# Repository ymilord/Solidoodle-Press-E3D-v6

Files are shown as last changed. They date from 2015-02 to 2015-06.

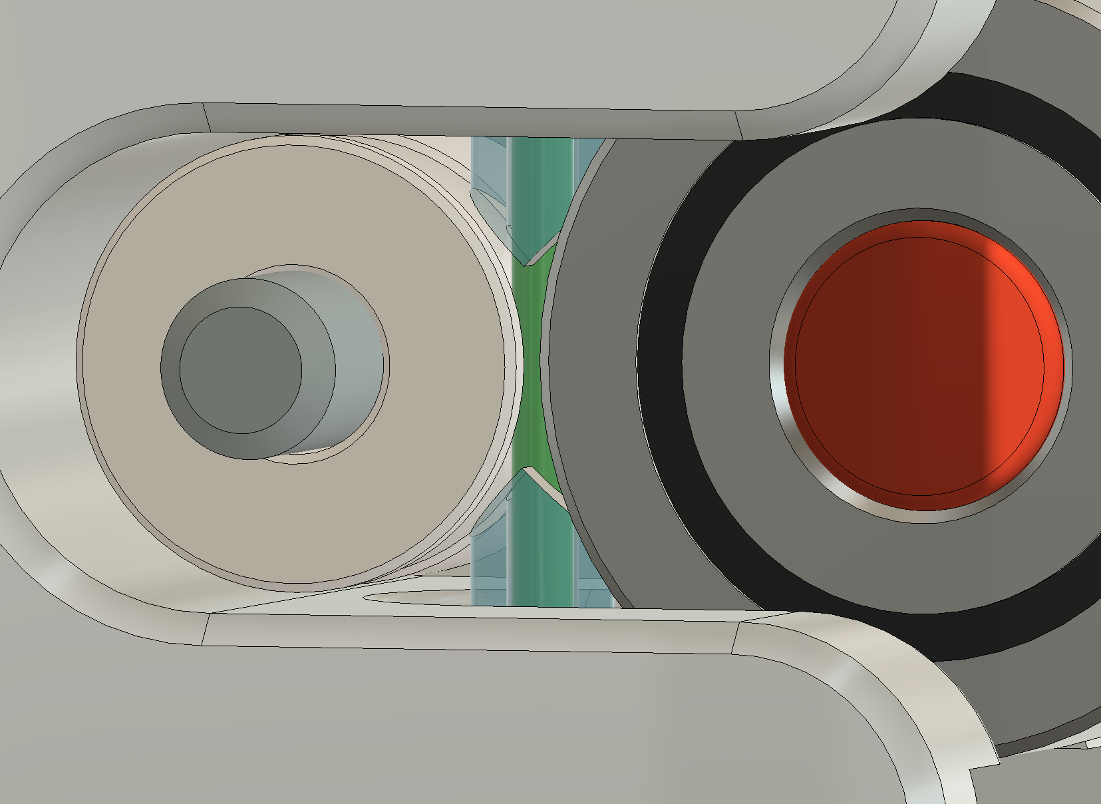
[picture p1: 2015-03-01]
Parts/Direct/SD2/Standard/SD2_Dual_PTFE_Tubes.jpg

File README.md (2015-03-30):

# E3D v6 Ready Firmware & Parts for the Soildoodle Press/SD2

This repo will have two versions. One Bowden and one direct drive. The in Firmware folder I've place a dump of the stock (shipping) firmware for the Press & a E3D Prepped verison. 

The main difference between the *Bowden* and the *Direct Drive* (aside from the bowden itself) is the Z-Height loss. In the bowden, Nothing changes - you will have the full 203mm travel for printing. For the Non-Bowden you will lose about 68mm of Z-Travel. So adjust your slicer app accordingly.

<b>Notice :</b> This is for the folks that are experienced in uploading arduino sketches/hex files to AVR's. If any of this sounds foreign or complicated- Not not attempt. <b>I will not provide support. Any damages/issues that you cause will be at your own risk.</b> (Sorry, got to say it.)

<b>Installation :</b>

This was done with a USBTinyISP connected to a RPI B+. (If you are using OctoPi and have a USBTinyISP this is by far the easiest method.) Of course there are other methods to do this. Use what ever workflow works best for you. This is a document of what I've done.

On the Press' controller, The right header is for the *ATTINY2313* (Pin 1 is right) the left header is for the *AT90USB1286* (Pin 1 is left). The *ATTINY2313* can be pulled directly (no jumpers) but the *AT90USB1286* needs a jumper in JP1 in order for you to read/write the firmware via the ICSP header.

If you want to make your own backup of the stock firmware, On the RPi create a folder where you'd like to store the backup. If you are using OctoPi I'd suggested creating a folder tree ~/pi/Press_Firmware/Stock/ & ~/pi/Press_Firmware/Modded/. 'Stock' to store the backup and 'Modded' to store the firmware provided here. 

To create your own backup run:

cd ~/pi/Press_Firmware/Stock/

avrdude -c avrisp -b 250000 -i 10 -p AT90USB1286 -P /dev/ttyACM0 -F -U flash:r:factory_press_AT90USB1286.hex:i

This will read the firmware on the Press and dump that data to a HEX file called 'factory_press_AT90USB1286.hex' in that folder.

To flash the modified firmware to the Press navigate to the folder where you placed the modded firmware. (i.e. ~/pi/Press_Firmware/Modded')

And run: 

avrdude -c avrisp -b 250000 -i 10 -p AT90USB1286 -P /dev/ttyACM0 -F -U flash:w:Solidoodle_Press_Modified_Firmware.cpp.hex:i

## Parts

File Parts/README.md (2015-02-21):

# Parts for Press.
STL & STEP files.

Printed @  0.2mm Layer height - 20% Infill - *8 Perimeters* - *8 Solid layers Top & Bottom* (*That's optional - I just used the same profile I use to print mounts of any kind. Just my personal preference.*) All designed to be printed as-is no supports.

This is a WIP (Work-In-Progess). I've uploaded the STL's & STEP files for the Bowden Config for the SD Press. The STEP's for the non-bowden soon to follow (I need to clean then up and label everything) As for the Non-Bowden verison. I am still designing the plug-in for the Z-Probe.

In the firmware folder, It has the INO & a precomplied HEX with changes to support the E3D v6 on the Press. Nothing else. 

Additional Parts Need :

Both : E3D v6 Universal /w Bowden Extras (Comes with a bowden tube) Then request either the 24V @ 25W or the 24V @ 40W Heater Cartridge. > http://www.filastruder.com/products/all-metal-e3d-v6-hotend
And x1 - VHR-2N - CONN HOUSING VH 2POS 3.96MM WH > http://www.digikey.com/product-search/en?mpart=VHR-2N&vendor=455
Bowden setup:

x2 M4 Screws @ 30mm - 2x M4 Nuts - 4x M3 Screws @ 30mm - x1 608ZZ bearing - x1 Spring (anything about 11mm in diameter) x2 Push-to-Connect Fitting (http://www.amazon.com/gp/product/B00PN5G2NQ/)

Non-Bowden Setup:

3x M3 Screws @ 30mm - 1x 608ZZ Bearing - 1x Spring (see above) 
I use a short piece of PTFE tubing that have a "V" shape at the top (see the example image for details.)

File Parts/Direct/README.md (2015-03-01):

This is a WIP - As in I am (as you read this) still finalizing the parts for this. This verison will work- But use at your own risk.

Added mount kit for the SD2. Same design and concept of the Press mount with an additional mount screw and a PTFE tube at the top for better flexible filament performance. This same updates will be applied to the Press Non-Bowden mount soon.
 
 **NOTE** : On the Press, I am still tweaking the mount/plug-in for the Z-Endstop for the Press to accomdate the height difference between the E3D v6 and the stock extruder. Also be mindful of the fact that you will lose some Z-height with this mod.

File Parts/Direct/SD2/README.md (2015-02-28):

This is a plate that attaches to the stock carriage to accept the non-bowden mount for an E3D v6. This plate has a 
wire channel for the connections for the heater cart. & thermistor.

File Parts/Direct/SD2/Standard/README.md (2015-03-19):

This is the SD2 E3D v6 mount for the standard hobbed gear.

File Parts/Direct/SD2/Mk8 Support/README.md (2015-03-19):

This is the SD2 E3D v6 mount with Mk8 support. This updated design has a PTFE tube in the lever to provide a better smoother path for flexible filaments like NinjaFlex. There is also a updated back plate thats thicker to prevent flex in the extruder assembly.

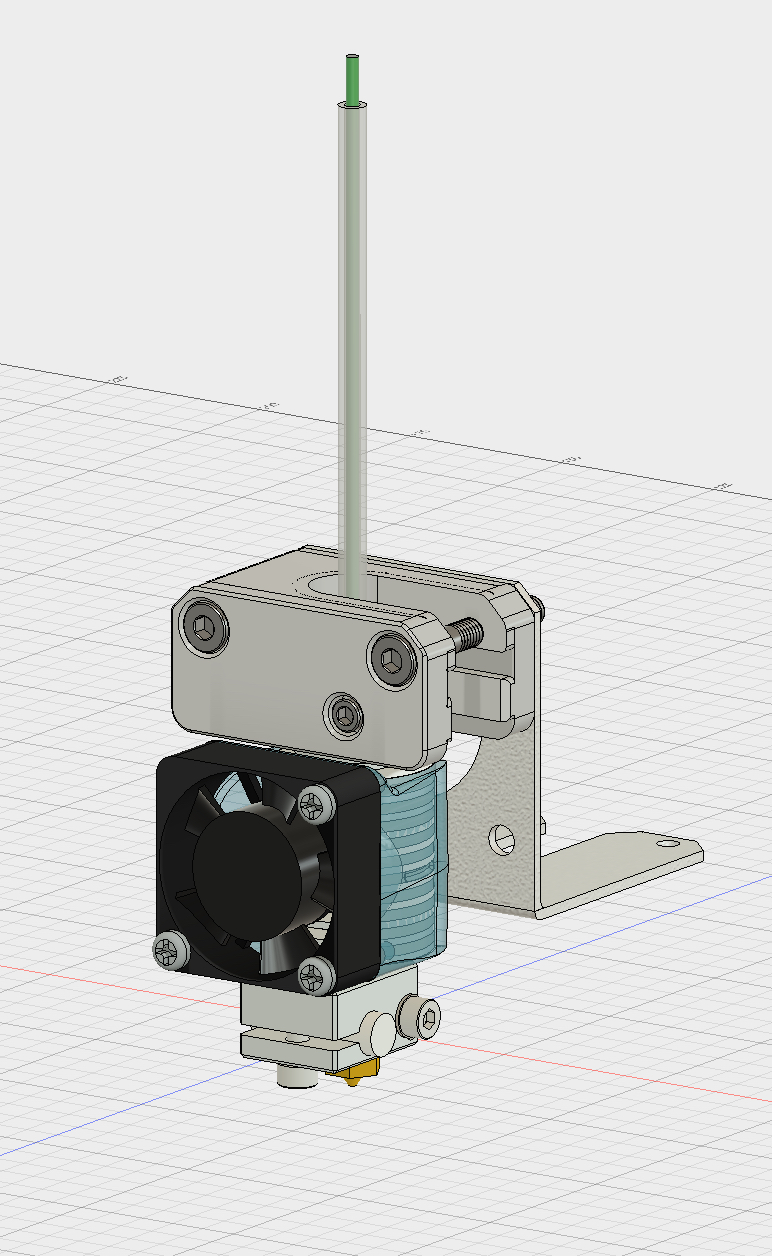
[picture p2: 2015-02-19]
Parts/Bowden/E3D_v6_Press_Mount.jpg

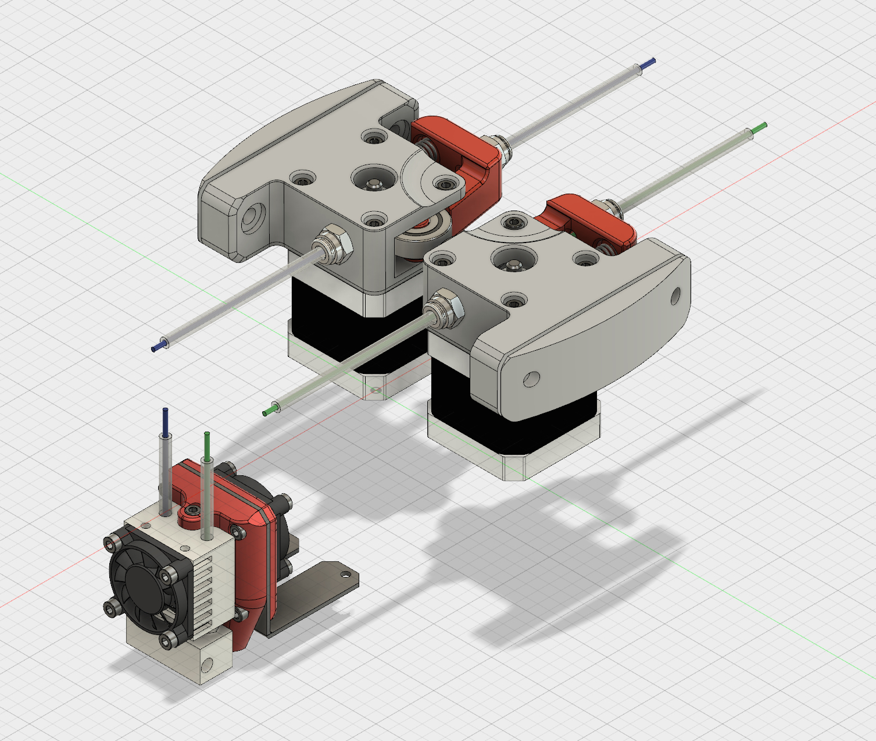
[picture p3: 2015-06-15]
Parts/Cyclops Parts/Cyclops_Mount.jpg

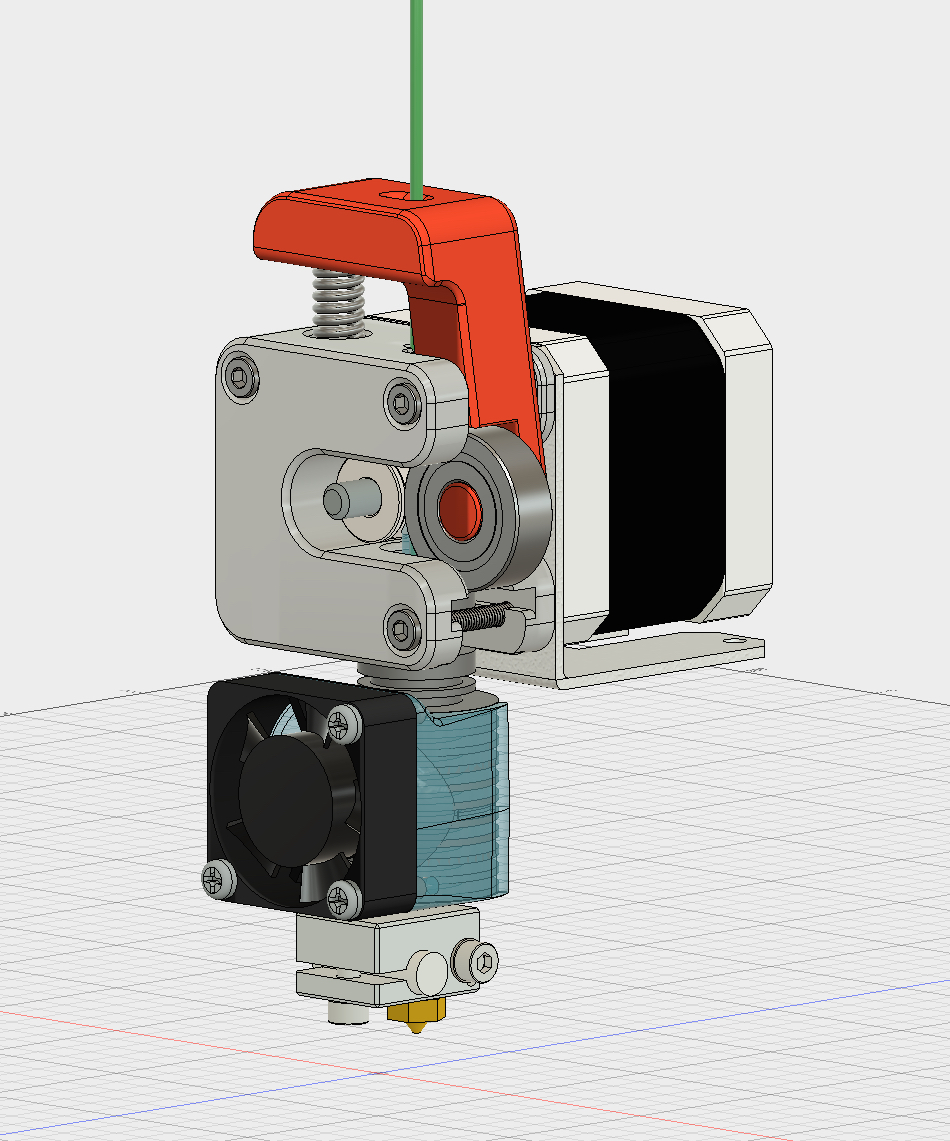
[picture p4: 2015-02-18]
Parts/Direct/Press/E3D_v6_Press_Non-Bowden_Mount.jpg

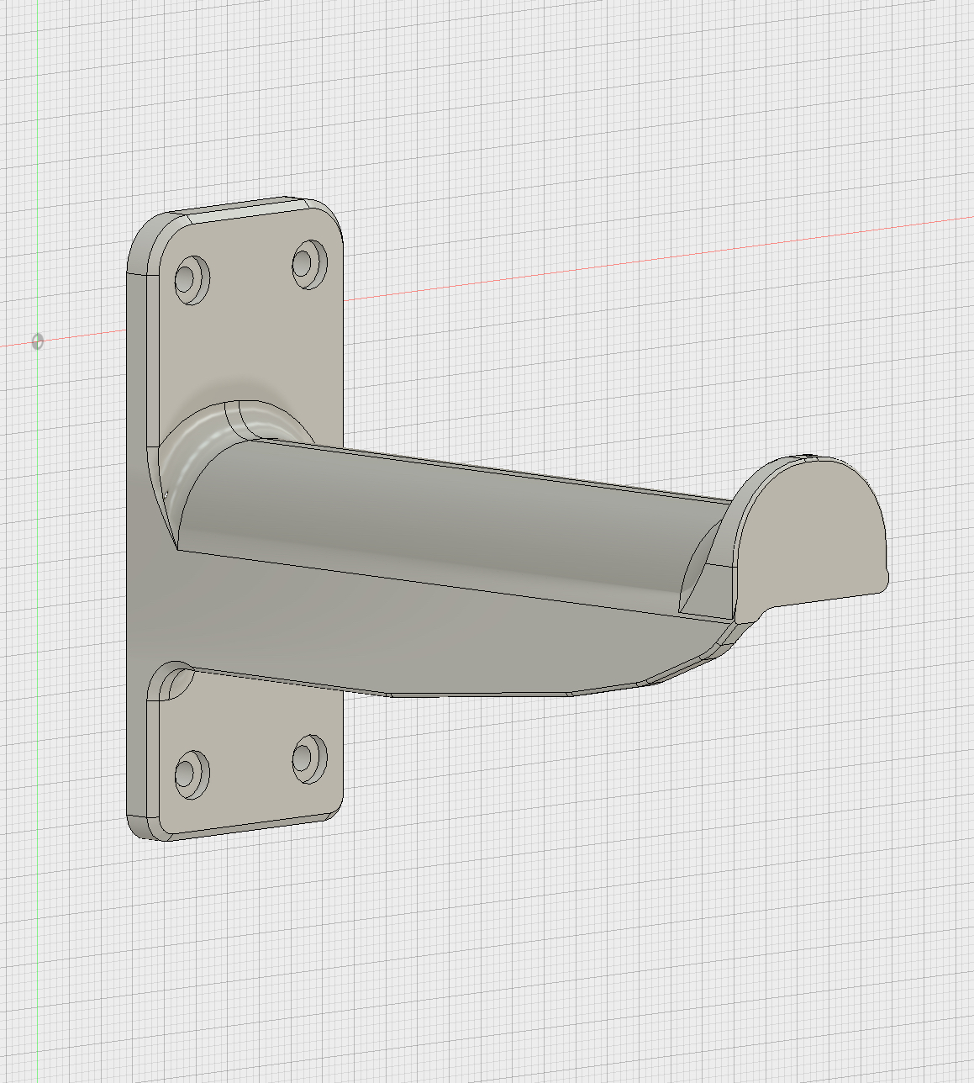
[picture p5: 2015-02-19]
Parts/Bowden/Bowden_Spool_Holder.jpg

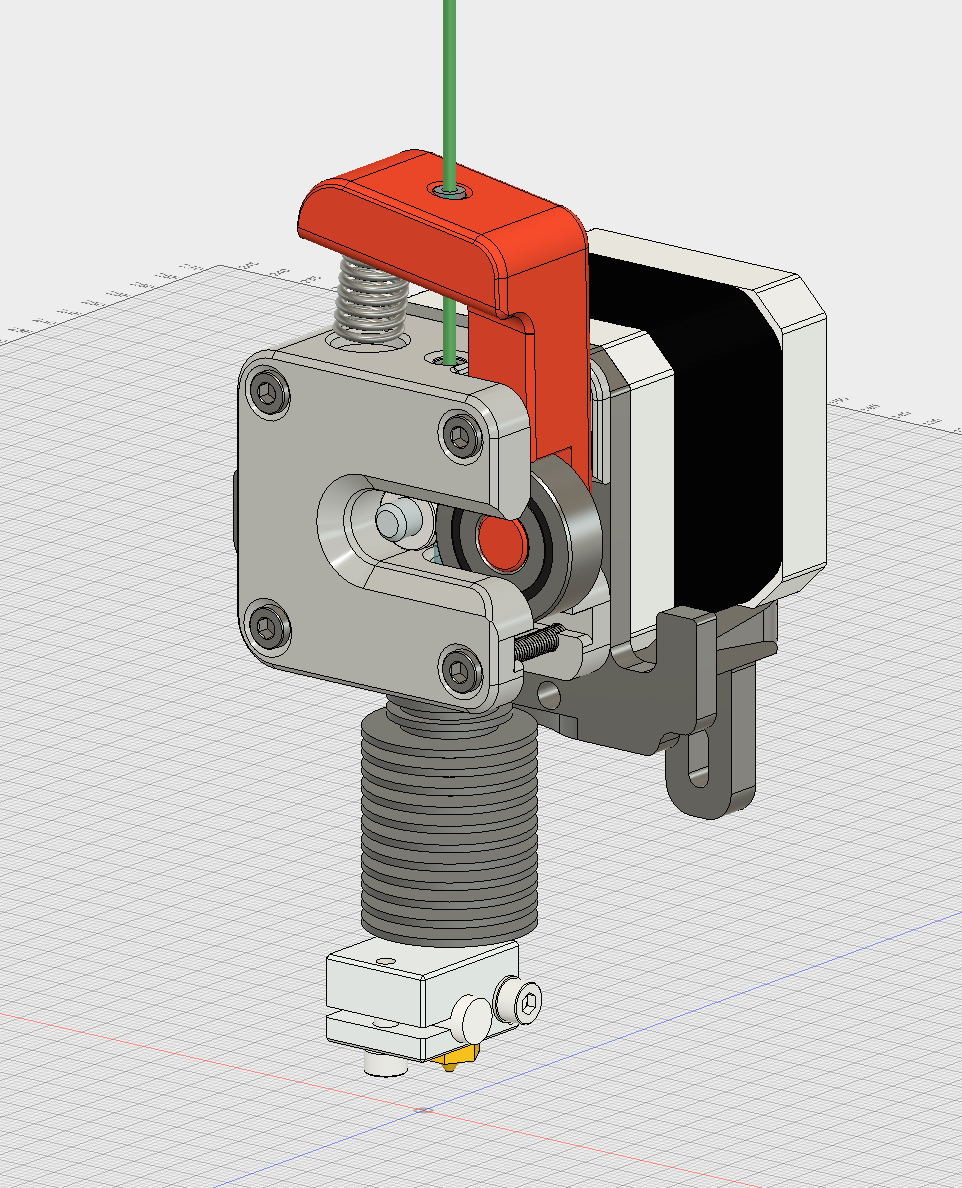
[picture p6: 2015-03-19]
Parts/Direct/SD2/Mk8 Support/SD2_Mk8_PTFE.jpg

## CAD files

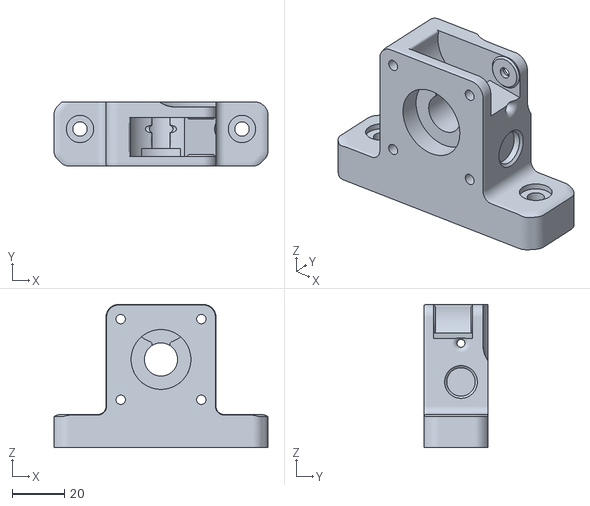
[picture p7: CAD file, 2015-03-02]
Parts/Bowden/STL/Bowden_Chassis.stl
82.3 x 24.7 x 55.0

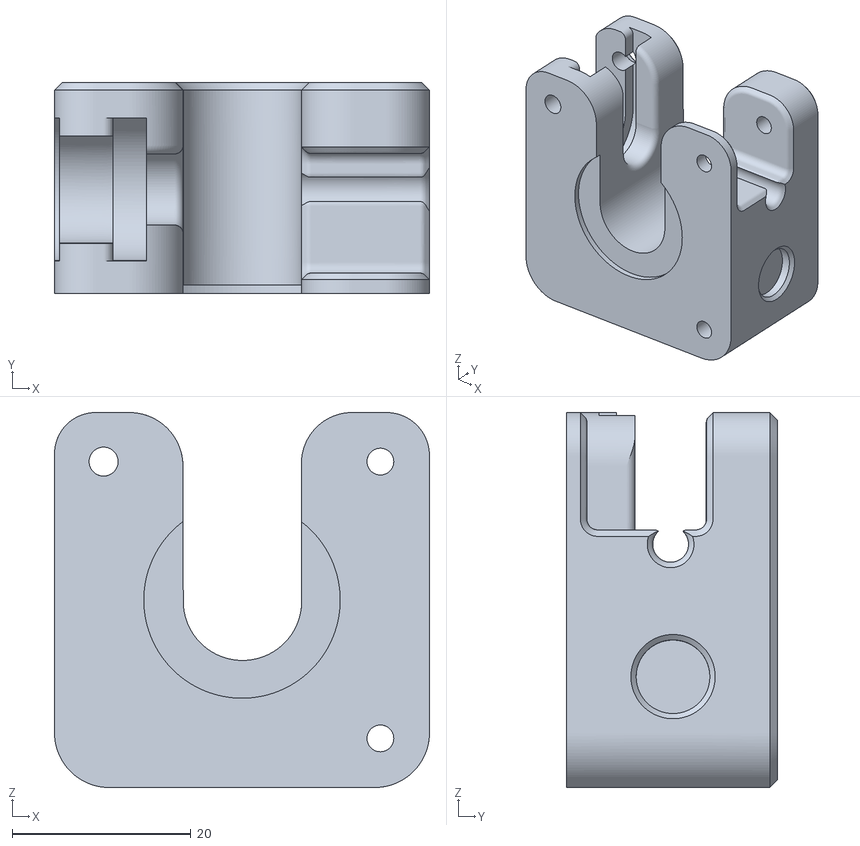
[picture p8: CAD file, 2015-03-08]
Parts/Direct/Press/STL/E3D_v6_Non-Bowden_Mount.stl
42.0 x 23.6 x 42.0

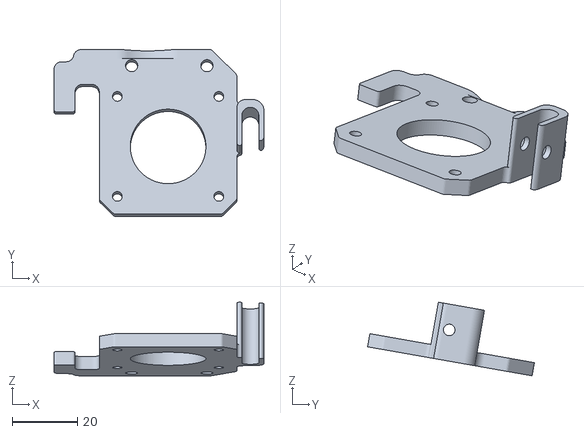
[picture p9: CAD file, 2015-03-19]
Parts/Direct/SD2/Mk8 Support/SD2_E3D_BACKPLATE.STL
64.1 x 51.0 x 22.5

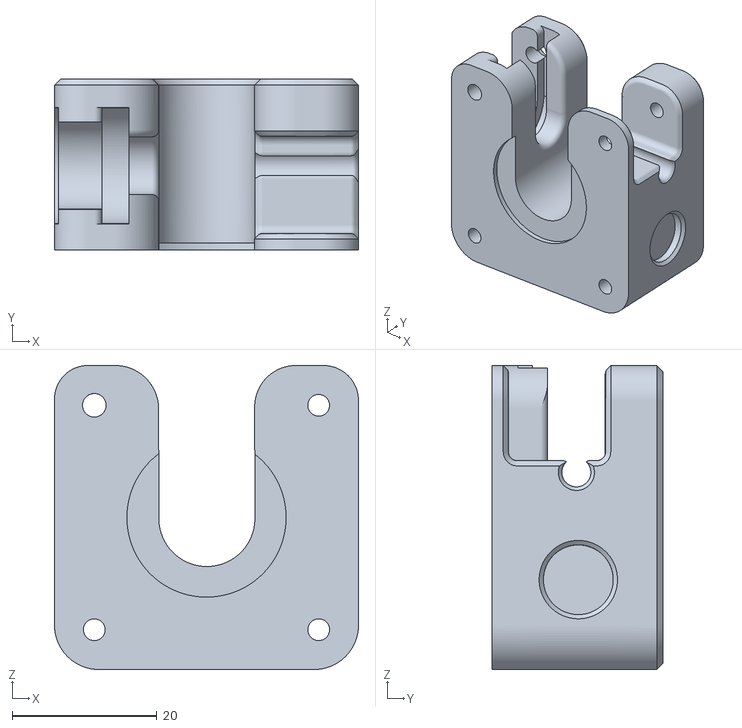
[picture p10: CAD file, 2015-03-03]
Parts/Direct/SD2/Standard/SD2 Non-Bowden E3D Mount.STL
42.0 x 23.6 x 42.0

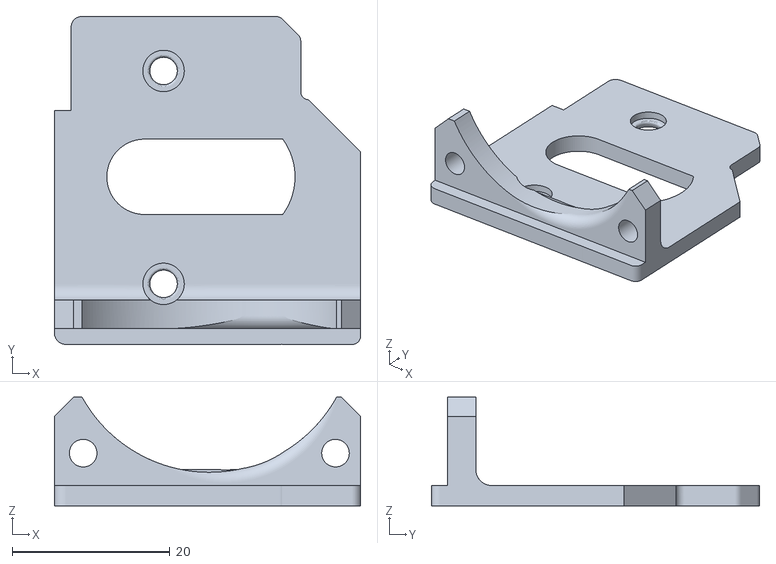
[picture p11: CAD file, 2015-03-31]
Parts/Filament Fan Mount for Press/Filamet 40mm Fan Mount for Press.STL
38.9 x 41.6 x 13.8

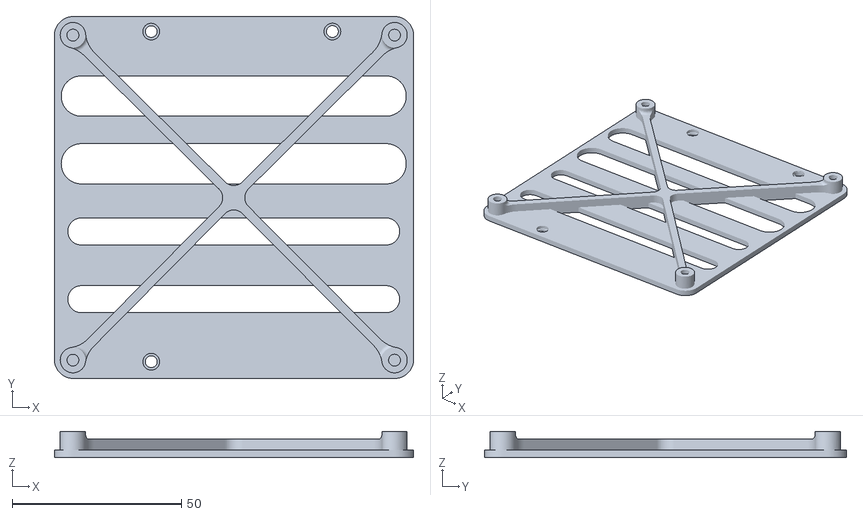
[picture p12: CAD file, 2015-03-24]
Parts/Mounts/SD2/SD2 RAMBo Mount.STL
106.1 x 106.9 x 7.72

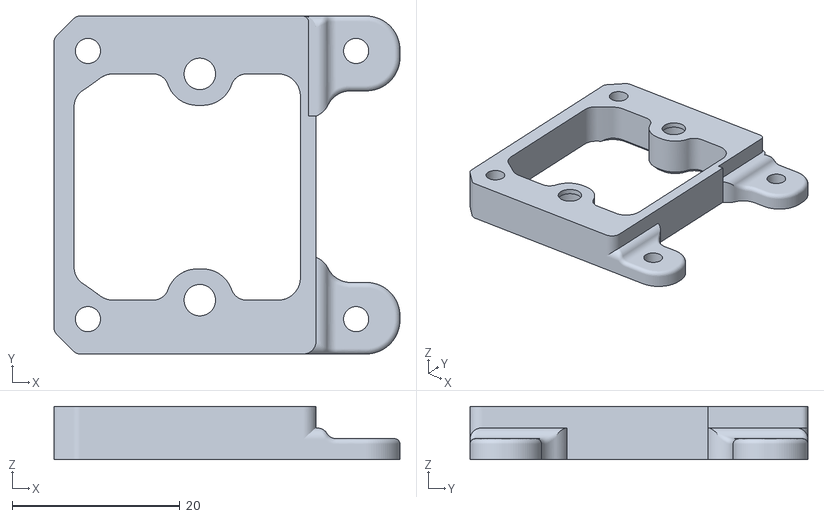
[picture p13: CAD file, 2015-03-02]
Parts/Press Fan Mount/Fan_Relocation_Mount.STL
41.3 x 40.3 x 6.35

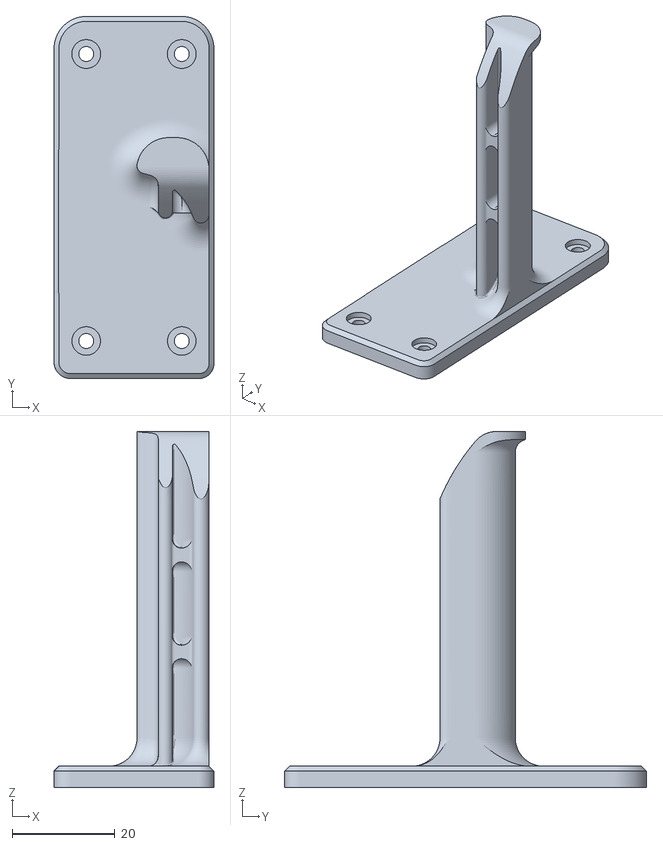
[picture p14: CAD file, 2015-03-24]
Parts/Spool Holder/Small Diameter Spool Holder.STL
31.1 x 70.3 x 69.1

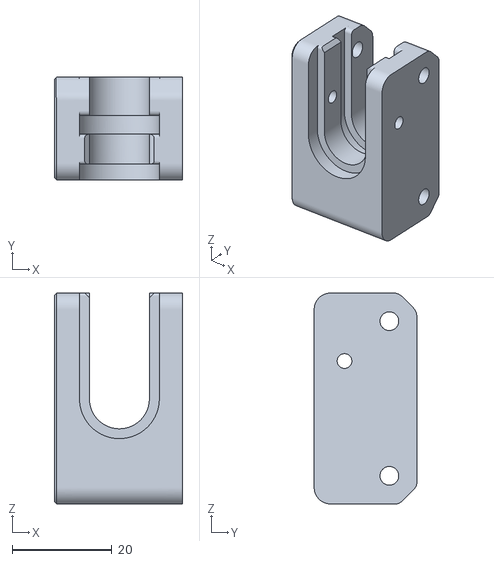
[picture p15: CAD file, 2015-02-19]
Parts/Bowden/STL/E3D_v6_Press_Mount.stl
25.8 x 20.6 x 42.3

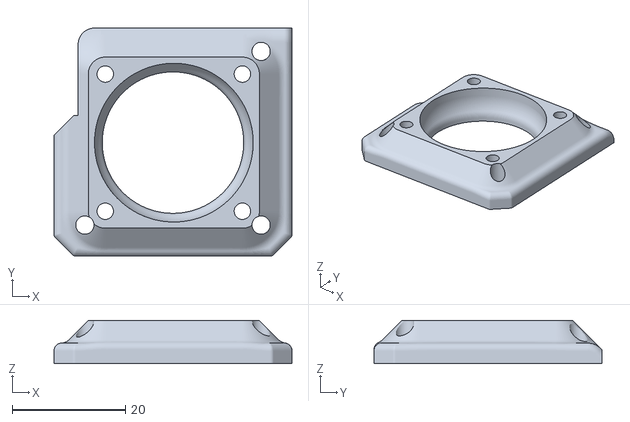
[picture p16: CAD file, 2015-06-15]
Parts/Cyclops Parts/Cyclops_Fan_Mount.stl
42.0 x 40.2 x 7.60

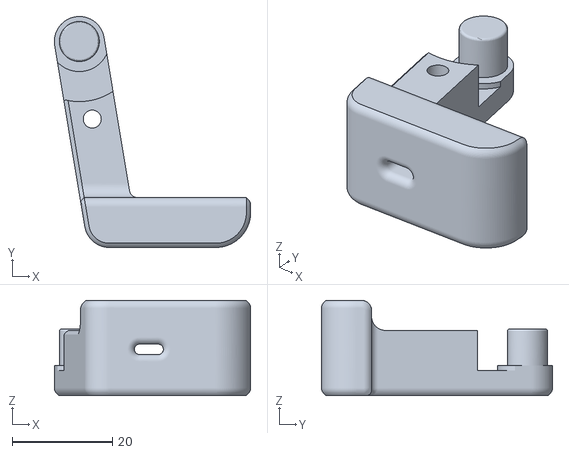
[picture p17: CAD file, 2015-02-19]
Parts/Direct/Press/STL/E3D_v6_Non-Bowden_Lever.stl
39.2 x 46.2 x 19.0

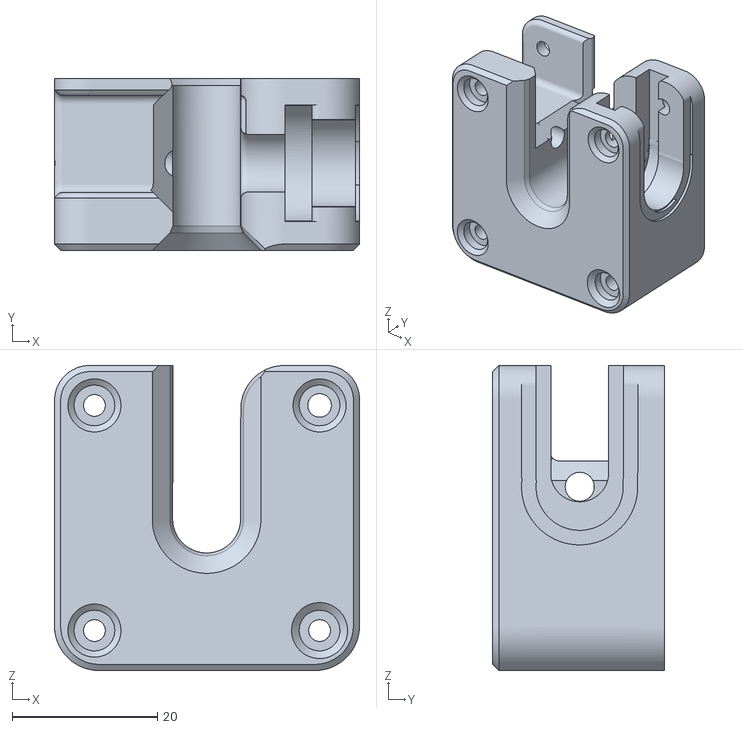
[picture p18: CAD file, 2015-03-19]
Parts/Direct/SD2/Mk8 Support/SD2_E3D_Mount_Mk8.STL
42.0 x 23.6 x 42.0

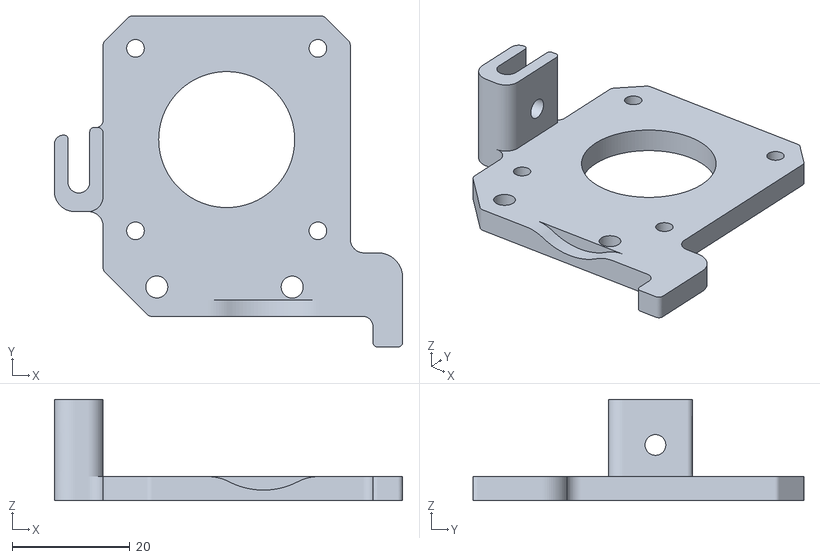
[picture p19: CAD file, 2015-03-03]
Parts/Direct/SD2/Standard/SD2 Mount Plate.STL
59.2 x 56.2 x 17.2

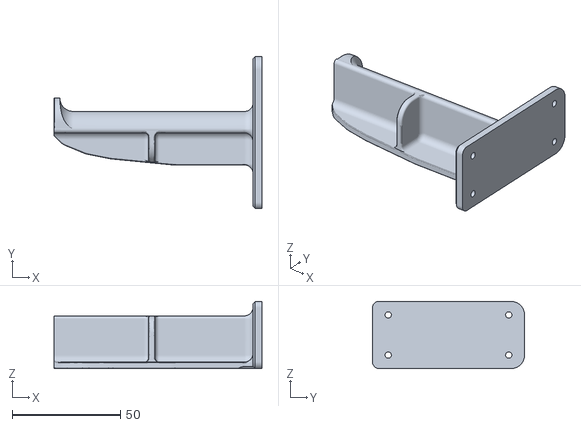
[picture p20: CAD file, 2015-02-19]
Parts/Spool Holder/Standard Spool Holder.stl
96.1 x 70.3 x 31.1

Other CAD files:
Parts/Cyclops Parts/Left_Side_Bowden.stl
Parts/Bowden/STL/Bowden_Lever.stl
Parts/Cyclops Parts/Left_Side_Shoe.stl
Parts/Direct/SD2/Mk8 Support/SD2_E3D_Lever_Mk8_PTFE.STL
Parts/Bowden/STL/Bowden_Chassis_Shoe.stl
Parts/Cyclops Parts/Cyclops_Press_Mount.stl
Parts/Cyclops Parts/Left_Side_Lever.stl
Parts/Cyclops Parts/Right_Side_Bowden.stl
Parts/Cyclops Parts/Right_Side_Lever.stl
Parts/Cyclops Parts/Right_Side_Shoe.stl
Parts/Direct/SD2/Standard/SD2 Lever.STL

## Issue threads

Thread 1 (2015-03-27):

Clarify Z-Height Loss

net127, 2015-03-27:
In README.md, it says:

"In the non-bowden, Nothing changes - you will have the full 203mm travel for printing. For the Non-Bowden you will lose about 68mm of Z-Travel. So adjust your slicer app accordingly."

I think you have one too many "nons" in there!

ymilord, 2015-03-27:
Thanks.

Closed 2015-03-27.

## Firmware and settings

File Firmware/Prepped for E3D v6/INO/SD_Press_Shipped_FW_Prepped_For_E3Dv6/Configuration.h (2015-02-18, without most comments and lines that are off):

#define CONFIGURATION_H
#define STRING_VERSION_CONFIG_H __DATE__  __TIME__ // build date and time
#define STRING_CONFIG_H_AUTHOR "RJD" // Who made the changes.
#define SERIAL_PORT 0
#define BAUDRATE 115200
#define MOTHERBOARD 81
#define CUSTOM_MENDEL_NAME "Solidoodle_Press"
#define EXTRUDERS 1
#define POWER_SUPPLY 1
#define TEMP_SENSOR_0 5
#define TEMP_SENSOR_1 0
#define TEMP_SENSOR_2 0
#define TEMP_SENSOR_BED 1
#define MAX_REDUNDANT_TEMP_SENSOR_DIFF 10
#define TEMP_RESIDENCY_TIME 5  // (seconds)
#define TEMP_HYSTERESIS 3       // (degC) range of +/- temperatures considered "close" to the target one
#define TEMP_WINDOW     1       // (degC) Window around target to start the residency timer x degC early.
#define HEATER_0_MINTEMP 5
#define HEATER_1_MINTEMP 5
#define HEATER_2_MINTEMP 5
#define BED_MINTEMP 5
#define HEATER_0_MAXTEMP 350
#define HEATER_1_MAXTEMP 275
#define HEATER_2_MAXTEMP 275
#define BED_MAXTEMP 130
#define PIDTEMP
#define BANG_MAX 255 // limits current to nozzle while in bang-bang mode; 255=full current
#define PID_MAX 255 // limits current to nozzle while PID is active (see PID_FUNCTIONAL_RANGE below); 255=full current
  #define PID_FUNCTIONAL_RANGE 10 // If the temperature difference between the target temperature and the actual temperature
  #define PID_INTEGRAL_DRIVE_MAX 255  //limit for the integral term
  #define K1 0.95 //smoothing factor within the PID
  #define PID_dT ((OVERSAMPLENR * 10.0)/(F_CPU / 64.0 / 256.0)) //sampling period of the temperature routine
  #define  DEFAULT_Kp 13
  #define  DEFAULT_Ki 0.7
  #define  DEFAULT_Kd 62
#define MAX_BED_POWER 255 // limits duty cycle to bed; 255=full current
#define PREVENT_DANGEROUS_EXTRUDE
#define PREVENT_LENGTHY_EXTRUDE
#define EXTRUDE_MINTEMP 170
#define EXTRUDE_MAXLENGTH (X_MAX_LENGTH+Y_MAX_LENGTH) //prevent extrusion of very large distances.
#define THERMAL_RUNAWAY_PROTECTION_PERIOD 60 //in seconds
#define THERMAL_RUNAWAY_PROTECTION_HYSTERESIS 5 // in degree Celsius
#define THERMAL_RUNAWAY_PROTECTION_BED_PERIOD 60 //in seconds
#define THERMAL_RUNAWAY_PROTECTION_BED_HYSTERESIS 5 // in degree Celsius
#define ENDSTOPPULLUPS // Comment this out (using // at the start of the line) to disable the endstop pullup resistors
  #define ENDSTOPPULLUP_XMAX
  #define ENDSTOPPULLUP_YMAX
  #define ENDSTOPPULLUP_ZMAX
  #define ENDSTOPPULLUP_XMIN
  #define ENDSTOPPULLUP_YMIN
  #define ENDSTOPPULLUP_ZMIN
const bool X_MIN_ENDSTOP_INVERTING = false; // set to true to invert the logic of the endstop.
const bool Y_MIN_ENDSTOP_INVERTING = false; // set to true to invert the logic of the endstop.
const bool Z_MIN_ENDSTOP_INVERTING = false; // set to true to invert the logic of the endstop.
const bool X_MAX_ENDSTOP_INVERTING = false; // set to true to invert the logic of the endstop.
const bool Y_MAX_ENDSTOP_INVERTING = false; // set to true to invert the logic of the endstop.
const bool Z_MAX_ENDSTOP_INVERTING = false; // set to true to invert the logic of the endstop.
#if defined(COREXY) && !defined(DISABLE_MAX_ENDSTOPS)
  #define DISABLE_MAX_ENDSTOPS
#endif
#define X_ENABLE_ON 0
#define Y_ENABLE_ON 0
#define Z_ENABLE_ON 0
#define E_ENABLE_ON 0 // For all extruders
#define DISABLE_X false
#define DISABLE_Y false
#define DISABLE_Z false
#define DISABLE_E false // For all extruders
#define DISABLE_INACTIVE_EXTRUDER true //disable only inactive extruders and keep active extruder enabled
#define INVERT_X_DIR true    // for Mendel set to false, for Orca set to true
#define INVERT_Y_DIR false    // for Mendel set to true, for Orca set to false
#define INVERT_Z_DIR false     // for Mendel set to false, for Orca set to true
#define INVERT_E0_DIR true   // for direct drive extruder v9 set to true, for geared extruder set to false
#define INVERT_E1_DIR false    // for direct drive extruder v9 set to true, for geared extruder set to false
#define INVERT_E2_DIR false   // for direct drive extruder v9 set to true, for geared extruder set to false
#define X_HOME_DIR 1
#define Y_HOME_DIR 1
#define Z_HOME_DIR -1
#define min_software_endstops true // If true, axis won't move to coordinates less than HOME_POS.
#define max_software_endstops true  // If true, axis won't move to coordinates greater than the defined lengths below.
#define X_MAX_POS 203
#define X_MIN_POS 0
#define Y_MAX_POS 200
#define Y_MIN_POS 0
#define Z_MAX_POS 200
#define Z_MIN_POS 0
#define X_MAX_LENGTH (X_MAX_POS - X_MIN_POS)
#define Y_MAX_LENGTH (Y_MAX_POS - Y_MIN_POS)
#define Z_MAX_LENGTH (Z_MAX_POS - Z_MIN_POS)
#define ENABLE_AUTO_BED_LEVELING // Delete the comment to enable (remove // at the start of the line)
  #define AUTO_BED_LEVELING_GRID
    #define LEFT_PROBE_BED_POSITION 50
    #define RIGHT_PROBE_BED_POSITION 150
    #define BACK_PROBE_BED_POSITION 150
    #define FRONT_PROBE_BED_POSITION 50
    #define AUTO_BED_LEVELING_GRID_POINTS 3
	#define PROBE_DOWN_ENTER 190
	#define PROBE_DOWN_EXIT  130
	#define PROBE_UP_ENTER    30
	#define PROBE_UP_EXIT     95
  #define X_PROBE_OFFSET_FROM_EXTRUDER -30.825
  #define Y_PROBE_OFFSET_FROM_EXTRUDER -5.45
  #define Z_PROBE_OFFSET_FROM_EXTRUDER 3.2
	  #define Z_PROBE_OFFSET_MIN 0
		#define Z_PROBE_OFFSET_MAX 10
  #define Z_RAISE_BEFORE_HOMING 15       // (in mm) Raise Z before homing (G28) for Probe Clearance.
  #define XY_TRAVEL_SPEED 8000         // X and Y axis travel speed between probes, in mm/min
  #define Z_RAISE_BEFORE_PROBING 15    //How much the extruder will be raised before traveling to the first probing point.
  #define Z_RAISE_BETWEEN_PROBINGS 2  //How much the extruder will be raised when traveling from between next probing points
  #define Z_SAFE_HOMING   // This feature is meant to avoid Z homing with probe outside the bed area.
    #define Z_SAFE_HOMING_X_POINT (X_MAX_LENGTH/2)    // X point for Z homing when homing all axis (G28)
    #define Z_SAFE_HOMING_Y_POINT (Y_MAX_LENGTH/2)    // Y point for Z homing when homing all axis (G28)
#define MANUAL_X_HOME_POS 203
#define MANUAL_Y_HOME_POS 200
#define MANUAL_Z_HOME_POS 0
#define NUM_AXIS 4 // The axis order in all axis related arrays is X, Y, Z, E
#define HOMING_FEEDRATE {50*60, 50*60, 5*60, 0}  // set the homing speeds (mm/min)
#define DEFAULT_AXIS_STEPS_PER_UNIT   {80,80,400,138}  // default steps per unit for Ultimaker
#define DEFAULT_MAX_FEEDRATE          {500, 500, 5, 25}    // (mm/sec)
#define DEFAULT_MAX_ACCELERATION      {1200,1200,100,10000}    // X, Y, Z, E maximum start speed for accelerated moves. E default values are good for Skeinforge 40+, for older versions raise them a lot.
#define DEFAULT_ACCELERATION          3000    // X, Y, Z and E max acceleration in mm/s^2 for printing moves
#define DEFAULT_RETRACT_ACCELERATION  3000   // X, Y, Z and E max acceleration in mm/s^2 for retracts
#define DEFAULT_XYJERK                20.0    // (mm/sec)
#define DEFAULT_ZJERK                 0.4     // (mm/sec)
#define DEFAULT_EJERK                 5.0    // (mm/sec)
#define EEPROM_SETTINGS
#define EEPROM_CHITCHAT
#define PLA_PREHEAT_HOTEND_TEMP 180
#define PLA_PREHEAT_HPB_TEMP 70
#define PLA_PREHEAT_FAN_SPEED 255   // Insert Value between 0 and 255
#define ABS_PREHEAT_HOTEND_TEMP 240
#define ABS_PREHEAT_HPB_TEMP 100
#define ABS_PREHEAT_FAN_SPEED 255   // Insert Value between 0 and 255
#define SOFT_PWM_SCALE 0
#define FILAMENT_SENSOR
#define FILAMENT_SENSOR_EXTRUDER_NUM	0  //The number of the extruder that has the filament sensor (0,1,2)
#define MEASUREMENT_DELAY_CM			14  //measurement delay in cm.  This is the distance from filament sensor to middle of barrel
#define DEFAULT_NOMINAL_FILAMENT_DIA  3.0  //Enter the diameter (in mm) of the filament generally used (3.0 mm or 1.75 mm) - this is then used in the slicer software.  Used for sensor reading validation
#define MEASURED_UPPER_LIMIT          3.30  //upper limit factor used for sensor reading validation in mm
#define MEASURED_LOWER_LIMIT          1.90  //lower limit factor for sensor reading validation in mm
#define MAX_MEASUREMENT_DELAY			20  //delay buffer size in bytes (1 byte = 1cm)- limits maximum measurement delay allowable (must be larger than MEASUREMENT_DELAY_CM  and lower number saves RAM)
#define DEFAULT_MEASURED_FILAMENT_DIA  DEFAULT_NOMINAL_FILAMENT_DIA  //set measured to nominal initially
#include "Configuration_adv.h"
#include "thermistortables.h"

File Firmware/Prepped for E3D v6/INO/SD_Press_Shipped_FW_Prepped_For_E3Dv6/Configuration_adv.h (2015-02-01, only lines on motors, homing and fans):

#define CONTROLLERFAN_PIN -1 //Pin used for the fan to cool controller (-1 to disable)
#define EXTRUDER_0_AUTO_FAN_PIN   -1
#define EXTRUDER_1_AUTO_FAN_PIN   -1
#define EXTRUDER_2_AUTO_FAN_PIN   -1
#define ENDSTOPS_ONLY_FOR_HOMING // If defined the endstops will only be used for homing
#define X_HOME_RETRACT_MM 5
#define Y_HOME_RETRACT_MM 5
#define Z_HOME_RETRACT_MM 1
#define MICROSTEP1 LOW,LOW
#define MICROSTEP2 HIGH,LOW
#define MICROSTEP4 LOW,HIGH
#define MICROSTEP8 HIGH,HIGH
#define MICROSTEP16 HIGH,HIGH
#define MICROSTEP_MODES {16,16,16,16,16} // [1,2,4,8,16]
#define DIGIPOT_MOTOR_CURRENT {135,135,135,135,135} // Values 0-255 (RAMBO 135 = ~0.75A, 185 = ~1A)
#define DIGIPOT_I2C_MOTOR_CURRENTS {1.0, 1.0, 1.0, 1.0, 1.0, 1.0, 1.0, 1.0}

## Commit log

2015-02-01 HEX Dump from both the AT90USB1286 & ATTINY2313
    This is the shipped firmware on both MCU’s on the Press.
2015-02-01 Renderings of the Mounts/Parts
    The idea is to place the bowden extruder in the filament bay of the
    press. All of this is WIP.
2015-02-01 Stock (Untouched) SD Provided FW for the Press.
    This is the stock untouched FW provided by Solidoodle for the Press.
    [Configuration.h, Configuration_adv.h, Menu Plans.xlsx]
2015-02-18 Added STL Files for E3D v6 Bowden Press Mount
    STL Files for the Bowden Setup for the Solidoodle Press.
    [Bowden_Chassis.stl, Bowden_Chassis_Shoe.stl, Bowden_Lever.stl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]
2015-02-19 Uploaded Corrected STL with proper orientation
    [Bowden_Chassis.stl, Bowden_Chassis_Shoe.stl, Bowden_Lever.stl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]
2015-02-19 Added Spool Holder for both Versions
    The Press kinda needs this.
    [Spool Holder.stl]
2015-02-19 Added Non-Bowden Parts
    This is a WIP - As in I am as you read this still finalizing the parts
    for this. Use at your own risk
    [E3D_v6_Non-Bowden_Lever.stl, E3D_v6_Non-Bowden_Mount.stl]
2015-02-19 Updated Image to match current Model
2015-02-19 Updated Image to match current models (Bowden)
2015-02-19 Clean up.
    [Configuration.h, Configuration_adv.h, Menu Plans.xlsx]
2015-02-19 Updated Images & Stock SD Firmware
    [Configuration.h, Configuration_adv.h, Menu Plans.xlsx]
2015-02-19 Fresh copy via Fusion with the proper orientation.
    [E3D_v6_Press_Mount.stl]
2015-02-19 Fresh export directly from fusion with the proper orientation.
    [E3D_v6_Press_Mount.stl]
2015-02-19 Added Example for the Short piece of PTFE with the "V" cut.
2015-02-21 Finalized & Cleaned STEP files for Bowden Config
    This is the ‘GM’ for the bowden files.
    [Bowden_Chassis.stp, E3D_v6_Press_Mount.stp]
2015-02-28 Added Mount Plate for SD2
    A plate that attaches to the existing carriage to accept the non-bowden
    E3D v6 mount.
    [SD2 Mount Plate.STL]
2015-02-28 Update and rename Parts/Non-Bowden/SD2 Mount Plate for Non-Bowden to Parts/Non-Bowden/SD2 Mount Plate for Non-Bowden/README.md
2015-02-28 Updated Mount
    Changed spacing between the hotend and the plate
    [SD2 Mount Plate.STL]
2015-03-01 Updated Image for SD2 Mount Plate
2015-03-01 Updated Mount
    Couple tweaks for the spring retention socket
    [E3D_v6_Non-Bowden_Mount.stl]
2015-03-01 Changed SD2 Direct Drive mount to be NinjaFlex Friendly
    Added a PTFE tube top and bottom for better flexible filament
    performance
    [E3D_v6_Non-Bowden_Lever.stl, E3D_v6_Non-Bowden_Mount.stl, SD2 Mount Plate.STL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]
2015-03-01 Added updated image of SD2 Mount
2015-03-01 Added updated Lever for SD2 E3D Mount
2015-03-01 Added STL ext. on Lever (Oops)
    [SD2 Lever.STL]
2015-03-02 NinjaFlex Friendly
    Changed the filament path. Decrease space around the hobbled gear and
    remove the filets around the inlet/outlet to help with filament bowing.
    [Bowden_Chassis.stl]
2015-03-02 Created a Fan mount to move the stock cooler to the front.
    This is to accommodate a 50x15mm blower in place of the stock fan. This
    then moves the stock fan in from of the stock extruder.
2015-03-02 Added a image of the mount
    [Fan_Relocation_Mount.STL]
2015-03-03 Minor Tweaks to the Mount
    Added a hole in the plate and mount for a M3 screw for better cable
    management.
    [SD2 Mount Plate.STL, SD2 Non-Bowden E3D Mount.STL]
2015-03-03 Changed hole size or wire retention screw
    [SD2 Mount Plate.STL, SD2 Non-Bowden E3D Mount.STL]
2015-03-08 Updated with PTFE Tube for inlet & outlet
    Better support for NinjaFLEX filaments.
    [E3D_v6_Non-Bowden_Mount.stl]
2015-03-08 Changed Folder Name
    ‘Non-Bowden’ to ‘Direct’
    [E3D_v6_Non-Bowden_Lever.stl, E3D_v6_Non-Bowden_Mount.stl, SD2 Lever.STL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]
2015-03-19 Added SD2 Mount with Mk8 Support
    Mk8 Support & Even better Flexible filament support.
    [SD2 Lever.STL, SD2 Mount Plate.STL, SD2 Non-Bowden E3D Mount.STL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]
2015-03-19 Added updated backplate for SD2 mount.
    [SD2_E3D_BACKPLATE.STL]
2015-03-24 30mm FAN Mount for Press
    [Filamet Fan Mount for Press.STL]
2015-03-24 Update File name for Filament Mount
    [Filamet 30mm Fan Mount for Press.STL]
2015-03-24 Added spool holder for smaller diameter spools
    [Small Diameter Spool Holder.STL, Standard Spool Holder.stl]
2015-03-24 Added SD2 RAMBo Mount
    [SD2 RAMBo Mount.STL]
2015-03-31 Added 40mm version
    [Filamet 40mm Fan Mount for Press.STL]
2015-06-15 Added Official update to SD Press FW
    (Forgot to push to GH)
    [Configuration.h, Configuration_adv.h, Menu Plans.xlsx]
2015-06-15 Added INO files with E3D changes
    [Configuration.h, Configuration_adv.h, Menu Plans.xlsx]
2015-06-15 Added Cyclops Parts
    [Cyclops_Fan_Mount.stl, Cyclops_Press_Mount.stl, Left_Side_Bowden.stl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]
